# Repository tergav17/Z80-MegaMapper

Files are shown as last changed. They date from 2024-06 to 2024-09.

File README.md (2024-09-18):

# Z80 MegaMapper

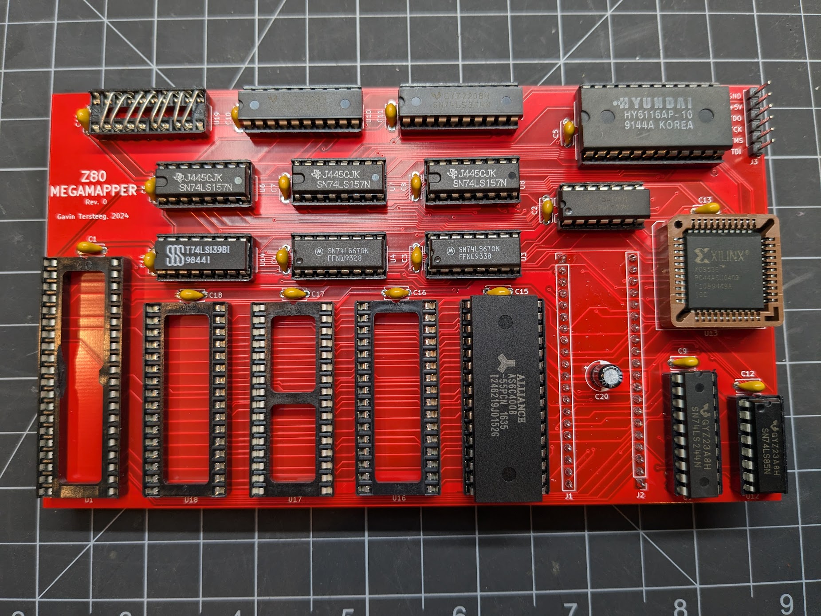
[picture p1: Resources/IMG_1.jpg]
Assembled ZMM


The Z80 MegaMapper (ZMM) is designed to enhance the ability of existing retro computers. This is done by interposing the Z80 CPU and intercepting certain signals. The current version of the MegaMapper provides the following enhancements:

- An additional 512 KB of static RAM, expandable up to 2 MB.
- Simple memory management, allowing the 4 independently selectable memory banks. Banks can also be write protected.
- Virtual machine mode, supporting “transparent” traps that do not depend on a specific stack pointer location.
- Fully programmable I/O space in virtual mode, allowing device addresses to be translated between the virtual and physical address space.
- I/O trap vector allowing any I/O instruction to be emulated by software if needed.
- Software controllable interrupts, allowing the maskable interrupt to be fully controlled by the real mode hypervisor.

The expanded memory is fairly self explanatory, but the other features may require a bit of explanation. The goal of the MegaMapper is to allow a Z80 machine to support “virtual machines”. These machines, with the help of a software hypervisor, can be made to seamlessly run software from other computer architectures. A single machine can act as an MSX, Colecovision, SG-1000, ZX81, Heathkit H8, TRS-80 Model II, TI-83, etc… simply by changing what hypervisor software is running. Additionally, virtual machines can be debugged in real time, to the point of being single-steppable. 

This is different from emulation as fundamentally everything is still executing on bare hardware. It provides vast software compatibility while still scratching the “retro hardware” itch that makes emulators simply not as fun (personally). In theory, this same type of device could have been built in the 80s with off-the-shelf components. All of the heavy lifting is still done by the ~3.5 Mhz Z80 processor.

Admittedly, emulation can always provide better results than a janky virtualization set up like this. This is more of a “Because I Can” project than anything else. 

# Virtual Machine Status

## SG-1000

The important parts of this seem to work. The PSG -> AY translation is passable, but it still needs some work in terms of tone and support for the noise channel. Pausing is also buggy due to lack of functional NMI.

## MSX 1

Boots to MSX basic just fine. Can also run all of the 32K cartridge ROMs I threw at it. Keyboard matrix still needs to be updated to support all keys.

# Current Issues

The Z80 data bus buffer currently doesn't work properly due to IM2-related shenanigans. The system works fine without it, so it may be omitted in a future revision.

At the moment, there is no way to maintain IFF2 contents during a trap. This is fine for systems that don't need an NMI, but can cause interrupt issues to those that do. It should be possible to add a status bit that keeps trick of if IFF1 and IFF2 are supposed to be equal, and work backwards from there.

The classic NMOS CPUs seem to have issues sometimes with detecting clock edges on the M1 cycle. Currently, this is circumvented by just getting a faster CMOS Z80.

# Installation

The ZMM is designed to slot directly into where the Z80 plugs into the mainboard of the host computer. Everything runs on +5V, so no additional jumpers are needed.

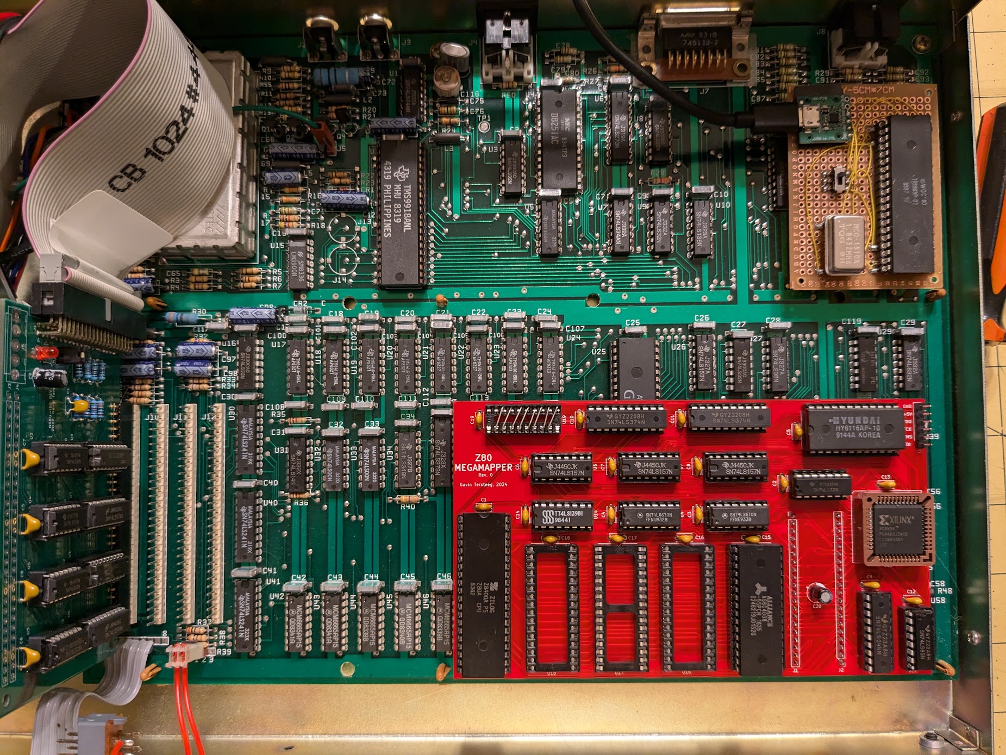
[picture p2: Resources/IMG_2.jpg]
ZMM Installed in a Nabu


# Limitations

One of the major design limitations of the ZMM is the fact that no provisions have been made for memory mapped I/O. Video RAM can crudely be accomplished by periodically scanning parts of memory and updating the VDP accordingly. This is very inefficient, especially the bigger the VRAM section gets. The size of the bankable sections is also limited to 16 KB, anything smaller will have to be emulated by manually copying sections of memory.

# BOM

| Quantity | Reference  | Part | Link |
| --- | --- | --- | ---- |
| 1 | U2 | 74LS32 | |
| 2 | U3, U4 | 74LS670 | |
| 1 | U5 | HM6116 | |
| 3 | U6..8 | 74LS157 | |
| 1 | U9 | 74LS244 | |
| 2 | U10, U11 | 74LS374 | |
| 1 | U12 | 74LS85 | |
| 1 | U13 | XC9536PC44 | |
| 1 | U14 | 74LS139 | |
| 1-4 | U15..18 | AS6C4008 | |
| 0 | U19 | 74LS245 | |
| 19 | C1..19 | 0.1 uF C | |
| 1 | C20 | 100 uF | |

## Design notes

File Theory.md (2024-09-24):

# Theory of Operation

The MegaMapper board works by intercepting Z80 bus signals and suppressing them to the larger system if necessary. How and when the signals are intercepted depends on what mode the MegaMapper is set in. The first of these modes is “Real Mode”. In this state, all memory signals will be passed to the Z80, and I/O signals will not be remapped. The 8 bytes of MegaMapper I/O space are still exposed, however. The trap state will be forced on in this mode. This is the default state of the machine and allows for original software to run unchanged.

The second mode that the machine can operate in is “Virtual Mode”. In this mode, memory operations are intercepted and sent to the onboard static RAM banks. All I/O signals will also be routed through the mapper table. How memory is laid out depends on if the MegaMapper is in the “Trap” state. If the trap state is active (this is always true by default), then memory looks like this:

- 0000-7FFF: Underlying System Memory
- 8000-BFFF: Mapper Table (256 byte blocks repeating)
- C000-FFFF: Virtual RAM Bank 3

When the trap state is reset, the memory map becomes the following:

- 0000-3FFF: Virtual RAM Bank 0
- 4000-7FFF: Virtual RAM Bank 1
- 8000-BFFF: Virtual RAM Bank 2
- C000-FFFF: Virtual RAM BANK 3

Each bank of virtual RAM can be mapped to one of up to 256 banks of onboard static RAM. The maximum amount of RAM that can be addressed this way is 4MB.

To exit out of the trap state, a `RETN` instruction must be executed (0xED45). The instruction will be executed normally, though the stack pointer will be constrained to a 4K window of memory. On the downward edge of the next M1 cycle, the trap state will be reset and memory access will be routed appropriately. It is important to ensure that the "I/O Violation Occured" latch is reset when doing this. Should this latch be set, only a single instruction will be executed before another trap occurs. The "I/O Violation Occured" latch can be reset by accessing the I/O trap vector while in the trap state.

When interrupt intercept mode is enabled and the trap state is reset, maskable interrupts are not directly sent to the CPU. They are instead used to generate traps, and the control register is used to directly manipulate the state of the maskable interrupt when untrapped.

There are a number of conditions that can start the trap response. These include a maskable interrupt during intercept mode (sampled at the beginning of an M1 cycle), or an I/O instruction accessing the trap address. When an I/O trap occurs, the “I/O Violation Occured” latch will be set. This condition will be sampled on the downward edge of the next M1 cycle of a new instruction. The status of the maskable interrupt pin will also be sampled if intercept mode in enabled. If either of these are asserted, then a trap will occur. It should be noted that both of these conditions are tied to the non-maskable interrupt pin. With a trap state is detected on the downward edge of the new M1 cycle, the trap state latch is set. Additionally, the “Address Capture” flip-flop will be set, forcing the memory accesses of the next M1 cycle to be constrained to a 4K window of memory (On the NABU, this is 0x7000-0x7FFF). This allows the return address to be recovered by the driver regardless of where the stack pointer is located in memory. The pushing of the return address also will not effect the contents of virtual memory. This flip-flop will be reset at the start of the next M1 cycle.

When not in trap mode, the MegaMapper will record the fetched byte at the end of every M1 cycle. This is so the hypervisor can mock I/O instructions as needed. Since only knowledge about what IN/OUT instruction has been executed is needed, the entire instruction is not encoded. Specifically, the bits are arranged as follows:

- 0: ISR Bit 0
- 1: ISR Bit 1
- 2: ISR Bit 3
- 3: ISR Bit 4
- 4: ISR Bit 5
- 5: ISR Bit 6
- 6: ISR Bit 7
- 7: I/O Violation Occured Latch

# Memory Map

The MegaMapper occupies 8 bytes of I/O space. On the NABU, this ranges from 0x30-0x37. Registers are as follows:

Memory map:
- 0x30 W: Bank register #0
- 0x31 W: Bank register #1
- 0x32 W: Bank register #2
- 0x33 W: Bank register #3
- 0x34 W: Control Register
- 0x30 R: Instruction Register
- 0x32 R: Address High Register
- 0x33 R: Address Low Register
- 0x37 R/W: Trap Vector

Bank register bits:
- 0-7: Bank select (128 total)
- 8: Write protect page

Instruction register bits
- 0-1: Last instruction opcode (Bits 0-1)
- 2-5: Last instruction opcode (Bits 3-6)
- 6: IFF Sync Bit
- 7: I/O trap occured latch

Control register bits:
- 0: Enable virtual mode
- 1: Translation table program direction (0 = OUT, 1 = IN)
- 2: IRQ intercept mode
- 3: Force maskable interrupt (intercept mode only)
- 4: N/A
- 5: N/A
- 6: N/A
- 7: N/A

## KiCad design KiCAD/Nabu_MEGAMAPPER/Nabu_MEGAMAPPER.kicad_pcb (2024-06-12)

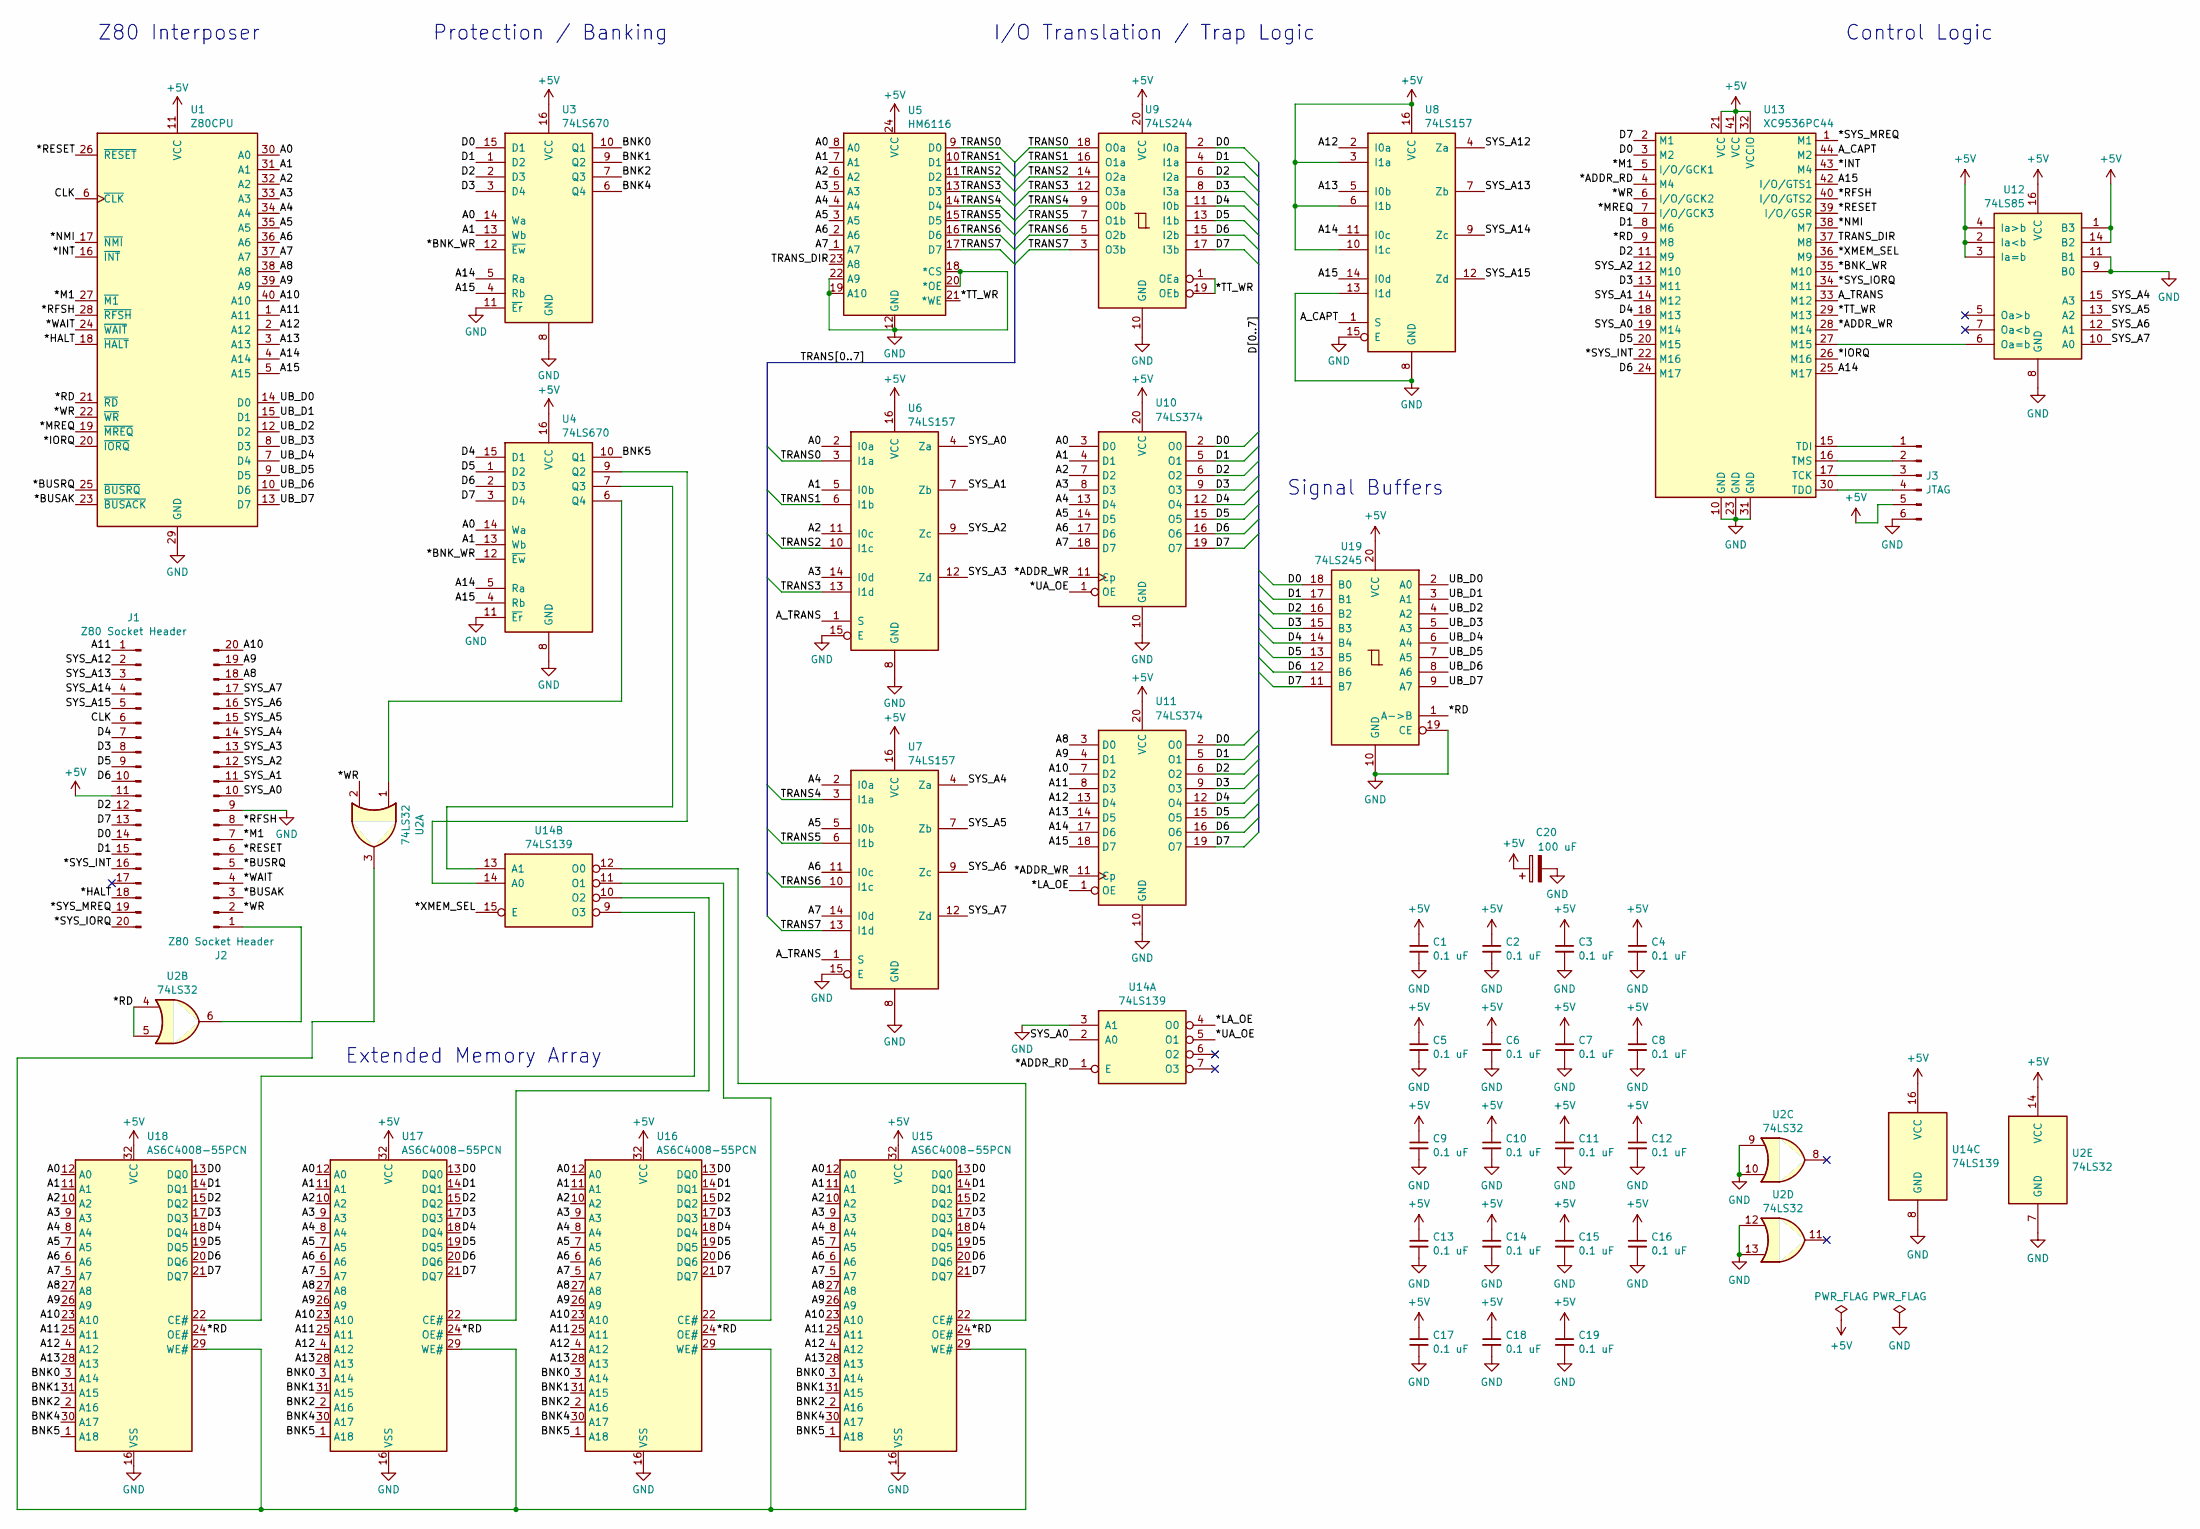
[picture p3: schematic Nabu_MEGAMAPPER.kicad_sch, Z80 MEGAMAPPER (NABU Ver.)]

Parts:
C1, C2, C3, C4, C5, C6, C7, C8, C9, C10, C11, C12, C13, C14, C15, C16, C17, C18, C19: 0.1 uF; C_Disc_D5.0mm_W2.5mm_P5.00mm
C20: 100 uF; CP_Radial_D6.3mm_P2.50mm
J1, J2: Z80 Socket Header; PinHeader_1x20_P2.54mm_Vertical
J3: JTAG; PinHeader_1x06_P2.54mm_Vertical
U1: Z80CPU; DIP-40_W15.24mm
U2: 74LS32; DIP-14_W7.62mm
U3, U4: 74LS670; DIP-16_W7.62mm
U5: HM6116; DIP-24_W15.24mm
U6, U7, U8: 74LS157; DIP-16_W7.62mm
U9: 74LS244; DIP-20_W7.62mm
U10, U11: 74LS374; DIP-20_W7.62mm
U12: 74LS85; DIP-16_W7.62mm
U13: XC9536PC44; PLCC-44_THT-Socket
U14: 74LS139; DIP-16_W7.62mm
U15, U16, U17, U18: AS6C4008-55PCN; DIP-32_W15.24mm
U19: 74LS245; DIP-20_W7.62mm

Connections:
+5V: C1.1, C2.1, C3.1, C4.1, C5.1, C6.1, C7.1, C8.1, C9.1, C10.1, C11.1, C12.1, C13.1, C14.1, C15.1, C16.1, C17.1, C18.1, C19.1, C20.1, J1.11, J3.5, U1.11 (VCC), U2.14 (VCC), U3.16 (VCC), U4.16 (VCC), U5.24 (VCC), U6.16 (VCC), U7.16 (VCC), U8.3 (I1a), U8.6 (I1b), U8.10 (I1c), U8.16 (VCC), U9.20 (VCC), U10.20 (VCC), U11.20 (VCC), U12.1 (B3), U12.2 (Ia<b), U12.3 (Ia=b), U12.4 (Ia>b), U12.14 (B2), U12.16 (VCC), U13.21 (VCC), U13.32 (VCCIO), U13.41 (VCC), U14.16 (VCC), U15.32 (VCC), U16.32 (VCC), U17.32 (VCC), U18.32 (VCC), U19.20 (VCC)
/*ADDR_RD: U13.4 (M4), U14.1 (E)
/*ADDR_WR: U10.11 (Cp), U11.11 (Cp), U13.28 (M14)
/*BNK_WR: U3.12 (~Ew), U4.12 (~Ew), U13.35 (M10)
/*BUSAK: J2.3, U1.23 (~BUSACK)
/*BUSRQ: J2.5, U1.25 (~BUSRQ)
/*HALT: J1.18, U1.18 (~HALT)
/*INT: U1.16 (~INT), U13.43 (M4)
/*IORQ: U1.20 (~IORQ), U13.26 (M16)
/*LA_OE: U11.1 (OE), U14.4 (O0)
/*M1: J2.7, U1.27 (~M1), U13.5 (I/O/GCK1)
/*MREQ: U1.19 (~MREQ), U13.7 (I/O/GCK3)
/*NMI: U1.17 (~NMI), U13.38 (M7)
/*RD: U1.21 (~RD), U2.4, U2.5, U13.9 (M8), U15.24 (OE#), U16.24 (OE#), U17.24 (OE#), U18.24 (OE#), U19.1 (A->B)
/*RESET: J2.6, U1.26 (~RESET), U13.39 (I/O/GSR)
/*RFSH: J2.8, U1.28 (~RFSH), U13.40 (I/O/GTS2)
/*SYS_INT: J1.16, U13.22 (M16)
/*SYS_IORQ: J1.20, U13.34 (M11)
/*SYS_MREQ: J1.19, U13.1 (M1)
/*TT_WR: U5.21 (*WE), U9.1 (OEa), U9.19 (OEb), U13.29 (M13)
/*UA_OE: U10.1 (OE), U14.5 (O1)
/*WAIT: J2.4, U1.24 (~WAIT)
/*WR: J2.2, U1.22 (~WR), U2.2, U13.6 (I/O/GCK2)
/*XMEM_SEL: U13.36 (M9), U14.15 (E)
/A0: U1.30 (A0), U3.14 (Wa), U4.14 (Wa), U5.8 (A0), U6.2 (I0a), U10.3 (D0), U15.12 (A0), U16.12 (A0), U17.12 (A0), U18.12 (A0)
/A1: U1.31 (A1), U3.13 (Wb), U4.13 (Wb), U5.7 (A1), U6.5 (I0b), U10.4 (D1), U15.11 (A1), U16.11 (A1), U17.11 (A1), U18.11 (A1)
/A2: U1.32 (A2), U5.6 (A2), U6.11 (I0c), U10.7 (D2), U15.10 (A2), U16.10 (A2), U17.10 (A2), U18.10 (A2)
/A3: U1.33 (A3), U5.5 (A3), U6.14 (I0d), U10.8 (D3), U15.9 (A3), U16.9 (A3), U17.9 (A3), U18.9 (A3)
/A4: U1.34 (A4), U5.4 (A4), U7.2 (I0a), U10.13 (D4), U15.8 (A4), U16.8 (A4), U17.8 (A4), U18.8 (A4)
/A5: U1.35 (A5), U5.3 (A5), U7.5 (I0b), U10.14 (D5), U15.7 (A5), U16.7 (A5), U17.7 (A5), U18.7 (A5)
/A6: U1.36 (A6), U5.2 (A6), U7.11 (I0c), U10.17 (D6), U15.6 (A6), U16.6 (A6), U17.6 (A6), U18.6 (A6)
/A7: U1.37 (A7), U5.1 (A7), U7.14 (I0d), U10.18 (D7), U15.5 (A7), U16.5 (A7), U17.5 (A7), U18.5 (A7)
/A8: J2.18, U1.38 (A8), U11.3 (D0), U15.27 (A8), U16.27 (A8), U17.27 (A8), U18.27 (A8)
/A9: J2.19, U1.39 (A9), U11.4 (D1), U15.26 (A9), U16.26 (A9), U17.26 (A9), U18.26 (A9)
/A10: J2.20, U1.40 (A10), U11.7 (D2), U15.23 (A10), U16.23 (A10), U17.23 (A10), U18.23 (A10)
/A11: J1.1, U1.1 (A11), U11.8 (D3), U15.25 (A11), U16.25 (A11), U17.25 (A11), U18.25 (A11)
/A12: U1.2 (A12), U8.2 (I0a), U11.13 (D4), U15.4 (A12), U16.4 (A12), U17.4 (A12), U18.4 (A12)
/A13: U1.3 (A13), U8.5 (I0b), U11.14 (D5), U15.28 (A13), U16.28 (A13), U17.28 (A13), U18.28 (A13)
/A14: U1.4 (A14), U3.5 (Ra), U4.5 (Ra), U8.11 (I0c), U11.17 (D6), U13.25 (M17)
/A15: U1.5 (A15), U3.4 (Rb), U4.4 (Rb), U8.14 (I0d), U11.18 (D7), U13.42 (I/O/GTS1)
/A_CAPT: U8.1 (S), U13.44 (M2)
/A_TRANS: U6.1 (S), U7.1 (S), U13.33 (M12)
/BNK0: U3.10 (Q1), U15.3 (A14), U16.3 (A14), U17.3 (A14), U18.3 (A14)
/BNK1: U3.9 (Q2), U15.31 (A15), U16.31 (A15), U17.31 (A15), U18.31 (A15)
/BNK2: U3.7 (Q3), U15.2 (A16), U16.2 (A16), U17.2 (A16), U18.2 (A16)
/BNK4: U3.6 (Q4), U15.30 (A17), U16.30 (A17), U17.30 (A17), U18.30 (A17)
/BNK5: U4.10 (Q1), U15.1 (A18), U16.1 (A18), U17.1 (A18), U18.1 (A18)
/CLK: J1.6, U1.6 (~CLK)
/D0: J1.14, U3.15 (D1), U9.2 (I0a), U10.2 (O0), U11.2 (O0), U13.3 (M2), U15.13 (DQ0), U16.13 (DQ0), U17.13 (DQ0), U18.13 (DQ0), U19.18 (B0)
/D1: J1.15, U3.1 (D2), U9.4 (I1a), U10.5 (O1), U11.5 (O1), U13.8 (M6), U15.14 (DQ1), U16.14 (DQ1), U17.14 (DQ1), U18.14 (DQ1), U19.17 (B1)
/D2: J1.12, U3.2 (D3), U9.6 (I2a), U10.6 (O2), U11.6 (O2), U13.11 (M9), U15.15 (DQ2), U16.15 (DQ2), U17.15 (DQ2), U18.15 (DQ2), U19.16 (B2)
/D3: J1.8, U3.3 (D4), U9.8 (I3a), U10.9 (O3), U11.9 (O3), U13.13 (M11), U15.17 (DQ3), U16.17 (DQ3), U17.17 (DQ3), U18.17 (DQ3), U19.15 (B3)
/D4: J1.7, U4.15 (D1), U9.11 (I0b), U10.12 (O4), U11.12 (O4), U13.18 (M13), U15.18 (DQ4), U16.18 (DQ4), U17.18 (DQ4), U18.18 (DQ4), U19.14 (B4)
/D5: J1.9, U4.1 (D2), U9.13 (I1b), U10.15 (O5), U11.15 (O5), U13.20 (M15), U15.19 (DQ5), U16.19 (DQ5), U17.19 (DQ5), U18.19 (DQ5), U19.13 (B5)
/D6: J1.10, U4.2 (D3), U9.15 (I2b), U10.16 (O6), U11.16 (O6), U13.24 (M17), U15.20 (DQ6), U16.20 (DQ6), U17.20 (DQ6), U18.20 (DQ6), U19.12 (B6)
/D7: J1.13, U4.3 (D4), U9.17 (I3b), U10.19 (O7), U11.19 (O7), U13.2 (M1), U15.21 (DQ7), U16.21 (DQ7), U17.21 (DQ7), U18.21 (DQ7), U19.11 (B7)
/SYS_A0: J2.10, U6.4 (Za), U13.19 (M14), U14.2 (A0)
/SYS_A1: J2.11, U6.7 (Zb), U13.14 (M12)
/SYS_A2: J2.12, U6.9 (Zc), U13.12 (M10)
/SYS_A3: J2.13, U6.12 (Zd)
/SYS_A4: J2.14, U7.4 (Za), U12.15 (A3)
/SYS_A5: J2.15, U7.7 (Zb), U12.13 (A2)
/SYS_A6: J2.16, U7.9 (Zc), U12.12 (A1)
/SYS_A7: J2.17, U7.12 (Zd), U12.10 (A0)
/SYS_A12: J1.2, U8.4 (Za)
/SYS_A13: J1.3, U8.7 (Zb)
/SYS_A14: J1.4, U8.9 (Zc)
/SYS_A15: J1.5, U8.12 (Zd)
/TRANS0: U5.9 (D0), U6.3 (I1a), U9.18 (O0a)
/TRANS1: U5.10 (D1), U6.6 (I1b), U9.16 (O1a)
/TRANS2: U5.11 (D2), U6.10 (I1c), U9.14 (O2a)
/TRANS3: U5.13 (D3), U6.13 (I1d), U9.12 (O3a)
/TRANS4: U5.14 (D4), U7.3 (I1a), U9.9 (O0b)
/TRANS5: U5.15 (D5), U7.6 (I1b), U9.7 (O1b)
/TRANS6: U5.16 (D6), U7.10 (I1c), U9.5 (O2b)
/TRANS7: U5.17 (D7), U7.13 (I1d), U9.3 (O3b)
/TRANS_DIR: U5.23 (A8), U13.37 (M8)
/UB_D0: U1.14 (D0), U19.2 (A0)
/UB_D1: U1.15 (D1), U19.3 (A1)
/UB_D2: U1.12 (D2), U19.4 (A2)
/UB_D3: U1.8 (D3), U19.5 (A3)
/UB_D4: U1.7 (D4), U19.6 (A4)
/UB_D5: U1.9 (D5), U19.7 (A5)
/UB_D6: U1.10 (D6), U19.8 (A6)
/UB_D7: U1.13 (D7), U19.9 (A7)
GND: C1.2, C2.2, C3.2, C4.2, C5.2, C6.2, C7.2, C8.2, C9.2, C10.2, C11.2, C12.2, C13.2, C14.2, C15.2, C16.2, C17.2, C18.2, C19.2, C20.2, J2.9, J3.6, U1.29 (GND), U2.7 (GND), U2.9, U2.10, U2.12, U2.13, U3.8 (GND), U3.11 (~Er), U4.8 (GND), U4.11 (~Er), U5.12 (GND), U5.18 (*CS), U5.19 (A10), U5.20 (*OE), U5.22 (A9), U6.8 (GND), U6.15 (E), U7.8 (GND), U7.15 (E), U8.8 (GND), U8.13 (I1d), U8.15 (E), U9.10 (GND), U10.10 (GND), U11.10 (GND), U12.8 (GND), U12.9 (B0), U12.11 (B1), U13.10 (GND), U13.23 (GND), U13.31 (GND), U14.3 (A1), U14.8 (GND), U15.16 (VSS), U16.16 (VSS), U17.16 (VSS), U18.16 (VSS), U19.10 (GND), U19.19 (CE)
unnamed: J2.1, U2.6
unnamed: J3.1, U13.15 (TDI)
unnamed: J3.2, U13.16 (TMS)
unnamed: J3.3, U13.17 (TCK)
unnamed: J3.4, U13.30 (TDO)
unnamed: U2.1, U4.6 (Q4)
unnamed: U12.6 (Oa=b), U13.27 (M15)
unnamed: U4.9 (Q2), U14.14 (A0)
unnamed: U4.7 (Q3), U14.13 (A1)
unnamed: U14.12 (O0), U15.22 (CE#)
unnamed: U14.11 (O1), U16.22 (CE#)
unnamed: U14.10 (O2), U17.22 (CE#)
unnamed: U14.9 (O3), U18.22 (CE#)
unnamed: U2.3, U15.29 (WE#), U16.29 (WE#), U17.29 (WE#), U18.29 (WE#)

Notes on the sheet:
Protection / Banking
Z80 Interposer
Extended Memory Array
Control Logic
I/O Translation / Trap Logic
Signal Buffers

Board: 2 copper layers, 42 parts (0 on the bottom side), 100 nets, no tracks yet.

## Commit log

2024-05-10 Inital commit
    [Nabu_MEGAMAPPER.kicad_pcb, Nabu_MEGAMAPPER.kicad_sch]
2024-05-11 Removed some of the 22V10s in favor of a CPLD
    [Nabu_MEGAMAPPER.kicad_sch]
2024-05-14 Continued work on schematic
    [Nabu_MEGAMAPPER.kicad_sch]
2024-05-18 Integrated register module with top level assembly
2024-05-30 Added full address capture logic to schematic
    [Nabu_MEGAMAPPER.kicad_sch]
2024-06-09 Started laying out MegaMapper PCB
    [Nabu_MEGAMAPPER.kicad_sch]
2024-06-10 Continued work on PCB layout
    [Nabu_MEGAMAPPER.kicad_pcb, Nabu_MEGAMAPPER.kicad_sch]
2024-06-11 Added bulk storage capacitor and started designing layout
    [Nabu_MEGAMAPPER.dsn, Nabu_MEGAMAPPER.kicad_pcb, Nabu_MEGAMAPPER.kicad_sch]
2024-06-12 Redid board layout for better routing
    [Nabu_MEGAMAPPER.dsn, Nabu_MEGAMAPPER.kicad_pcb]
2024-06-13 Added routing and gerbers
    [Nabu_MEGAMAPPER-B_Cu.gbr, Nabu_MEGAMAPPER-B_Mask.gbr, Nabu_MEGAMAPPER-B_Paste.gbr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]
2024-06-18 Added assembly.ucf file
2024-07-11 Switched untrap logic to use RETN
2024-07-11 Updated final assembly JED file
2024-07-13 Added images of finished boards
2024-07-28 Modified assembly to pass some signals directly through
2024-07-28 V2 of test assembly
2024-07-29 V3 of test assembly
2024-07-29 V4 version of test assembly
2024-07-29 V5 version of test assembly
2024-08-31 Started work on interrupt interception
2024-09-01 Updated VM to use virtual interrupts instead of passthru
2024-09-04 Inital version of SN76489 driver
2024-09-08 MSX core keyboard driver update
2024-09-24 Started work on block device interace
2024-09-25 Function prototypes for block devices
